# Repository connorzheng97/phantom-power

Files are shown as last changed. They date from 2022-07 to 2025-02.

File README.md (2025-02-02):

# What is this

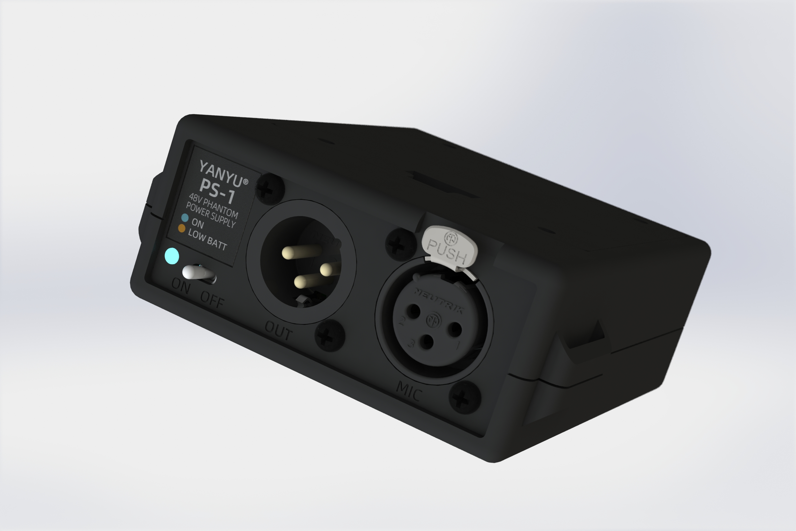
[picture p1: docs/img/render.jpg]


This is a 3-AA-battery powered phantom power supply. It was intended for use with wireless microphone beltpacks to provide high quality 48V phantom power to large condenser microphones and enable them to be used wirelessly, or as a standalone unit. It's also suitable for DI boxes, small condenser microphones and anything requiring phantom power.

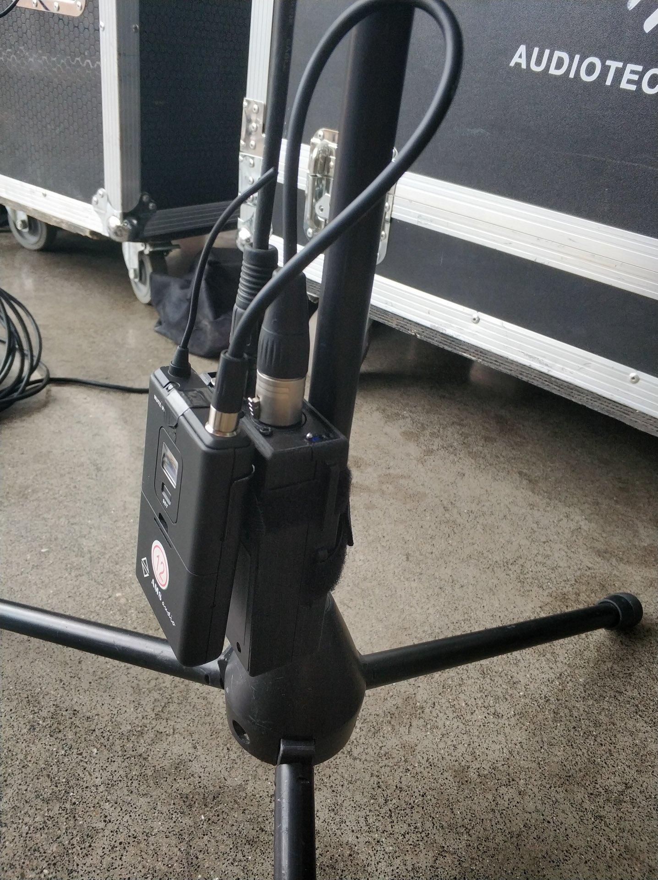
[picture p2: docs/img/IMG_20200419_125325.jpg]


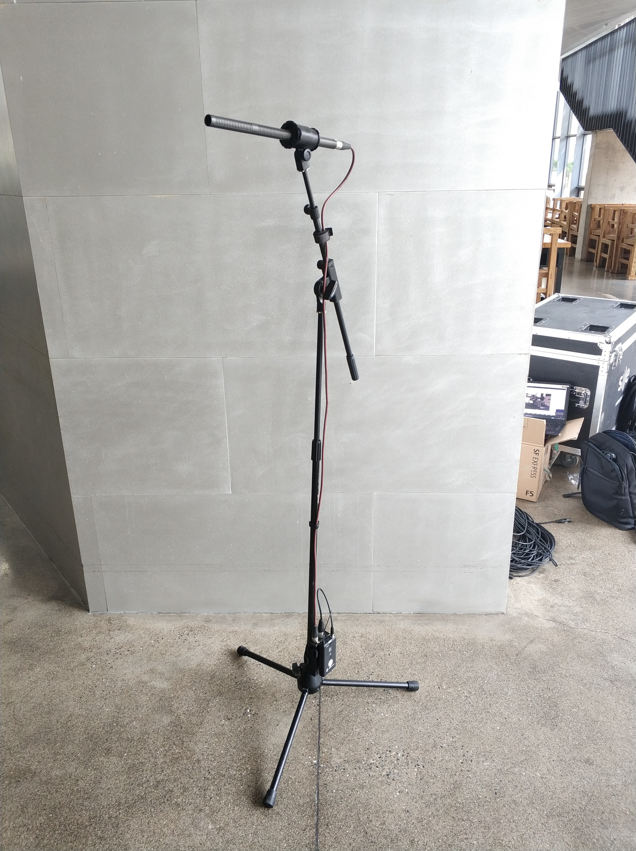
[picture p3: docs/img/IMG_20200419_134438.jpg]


This is a complete design with schematic, PCB and enclosure. Files are production-ready, with BOM. Design of this project begun in 2019 and final test was done on December of 2021. Batch production was planned but hasn't been carried out, as newer wireless microphone beltpacks has begun to incorporate built-in phantom power circuits (although usually not at full 48V), and COVID has had a major impact on touring industry.

# The Specs
- Power Source: 3x AA Batteries, alkaline is recommended. Ni-Mh rechargeable can also be used.
- Battery Run Time: depends on load and actual battery capacity, 5 to 72 hours typically
- Battery Indicator: yes, two LEDs for normal and low battery
- Power Output: IEC 61938, 48VDC ±2V
- Phantom Resistor: 6.81K
- Current: up to about 14mA at short-circuit
- Noise: < 100uVpp
- EMI: not tested

# The Design
## Overall Design

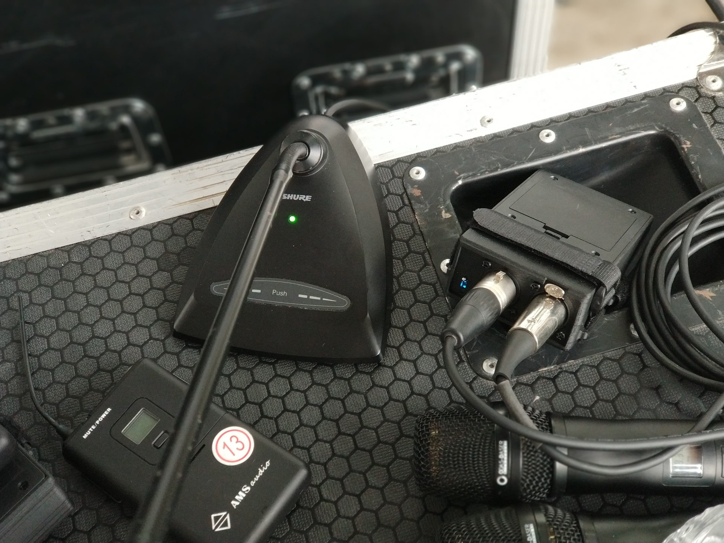
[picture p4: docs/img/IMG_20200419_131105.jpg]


A simple power supply box with XLR-in (connects to device requiring phantom power), XLR-out (no DC bias, connect to audio input of next stage), a power switch and a battery voltage indicator. The switch is partly recessed to avoid accidental operation. The colors of the battery indicator are ice-blue and orange, which are color-blind friendly. On the side of the box are 2 ears where you can thread in a hook-and-loop nylon cable tie to form a loop and strap the box to wireless beltpack and microphone stand or other fixation points.

## Schematic and PCB
Schematic and PCB were done with KiCAD 5. A [PDF version of the schematic](./docs/phantom_v1.pdf) is available for view under the `docs` folder.

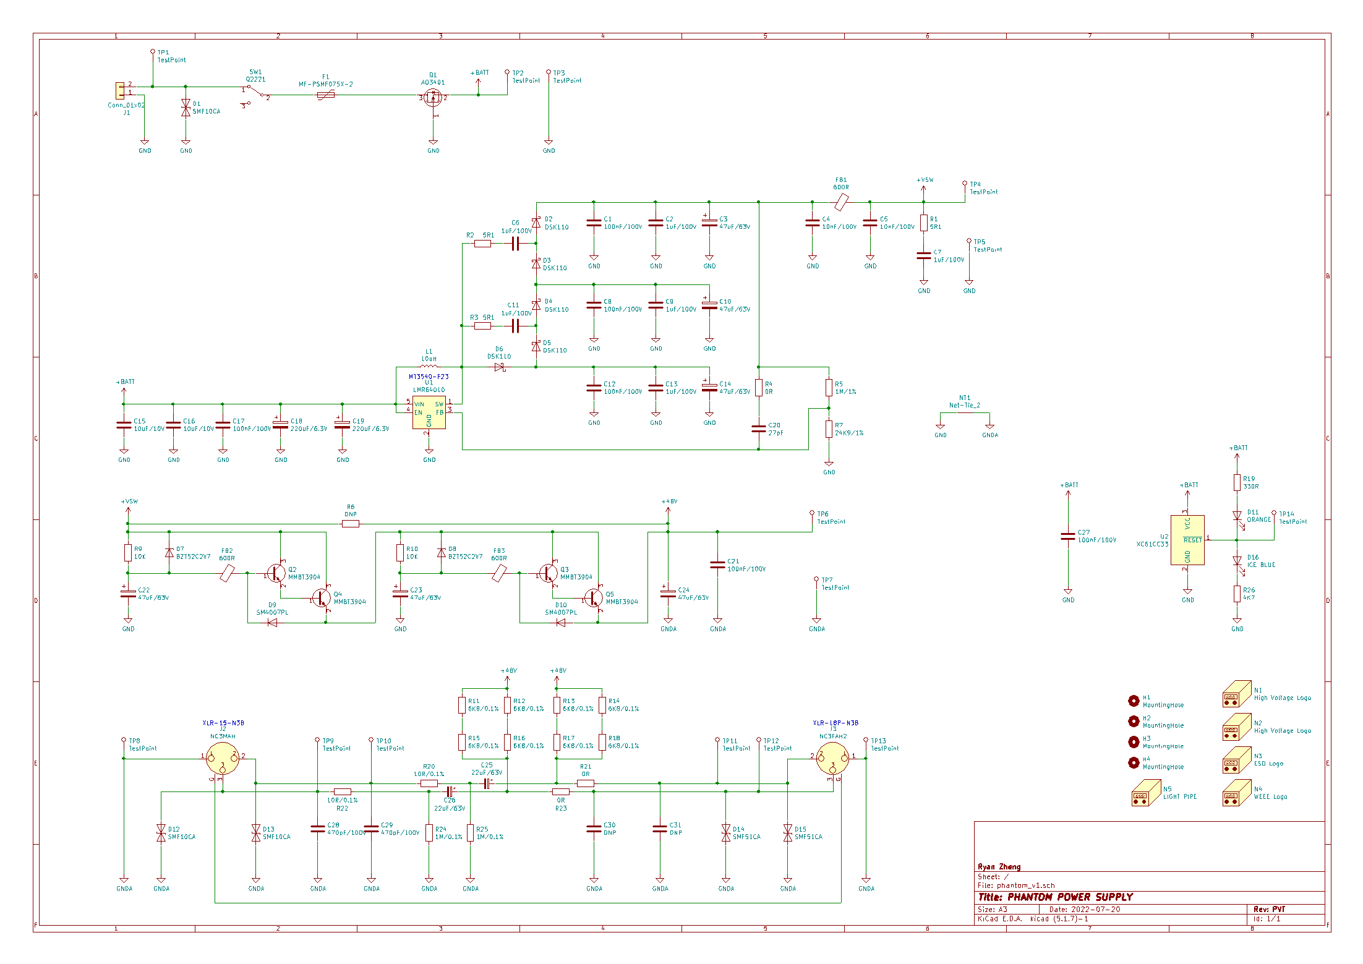
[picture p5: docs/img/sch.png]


Circuit consists of a simple boost converter with added 3-stage diode voltage multiplier, a high voltage LDO, and a 2-stage Darlington capacitance multiplier for lowest noise possible. Protection circuitry and battery voltage indication were also added. A P-MOS blocks reverse battery, followed by a PPTC resettable fuse and transient suppression.

PCB is a normal 1.6mm 2-layer PCB.

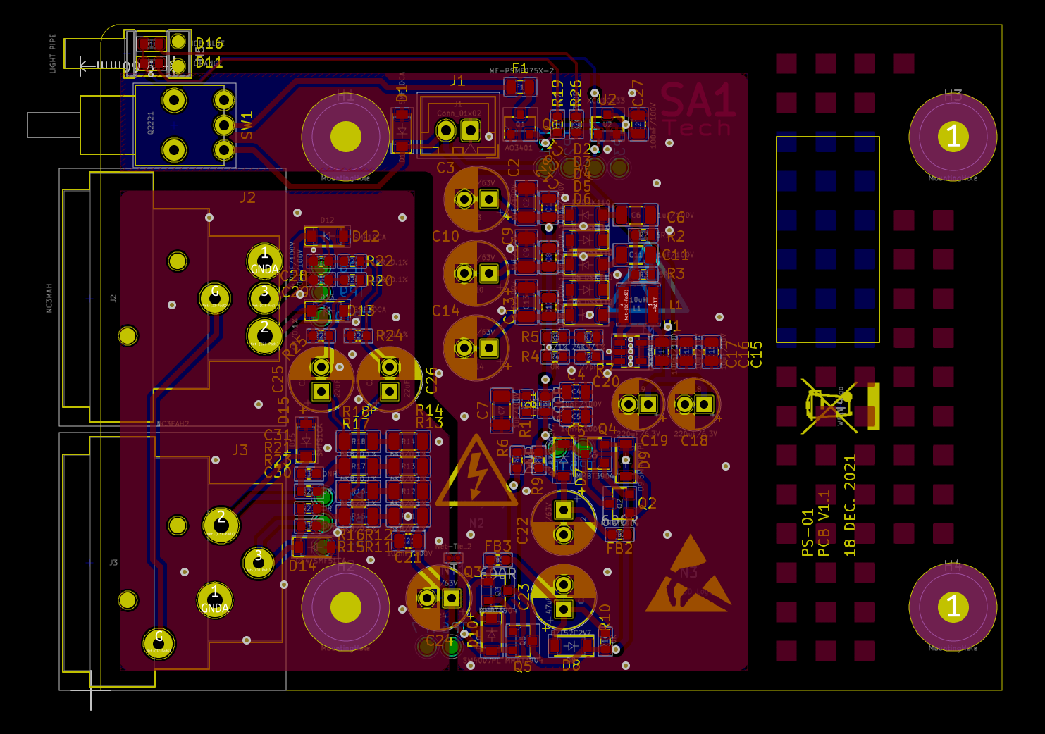
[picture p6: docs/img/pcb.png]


## Mechanical Design
Enclosure design was done with Solidworks 2018. STEP and STL files are also provided in the `mech` folder. The design is mostly complete, and should be injection-molding ready, with no draft angle in design file. 

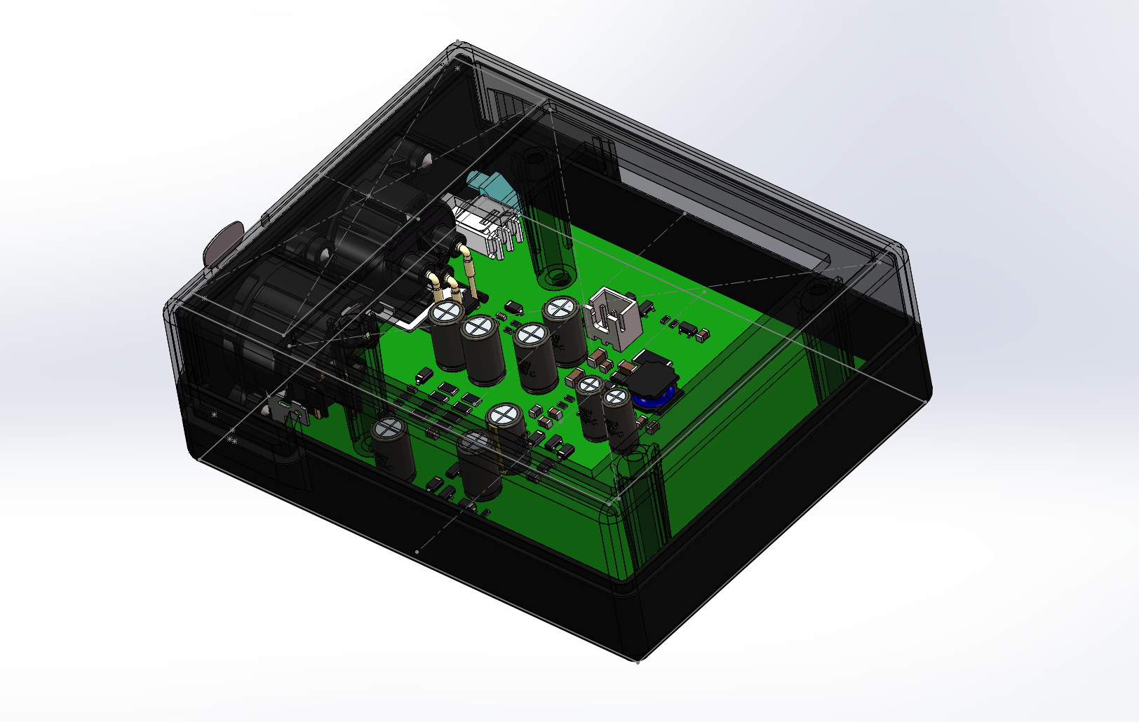
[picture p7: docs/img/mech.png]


The PCB is held down to the base part by boss from top part, which are held down to base part by self-tapping screws. The holes in the bosses are through, which are also used to mount the battery holder. The front panel is held in place by groves on both large parts. The battery holder is an off-the-shelf one which can be bought on Taobao or AliExpress. XLR connectors are fixed to front panel with self-tapping screws.

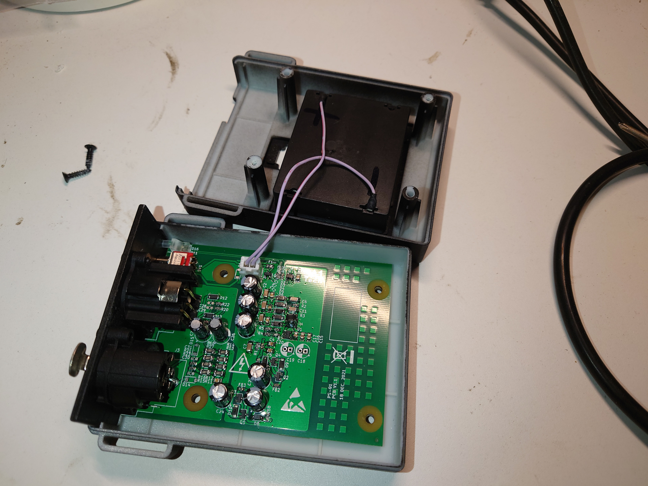
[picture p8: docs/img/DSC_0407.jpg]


# Make Your Own
You can fabricate the PCB and have it partly assembled by a PCB fab such as PCBWay(JDB PCB) or JLC-PCB. Solder only the common SMT parts at the fab, which I found to be the most cost-saving. A gerber file set is included in the `output` folder in the hardware design files. Other parts can be sourced from LCSC or another distributor. Hand soldering is mostly easy except the VSSOP LDO may be a little bit annoying. Alternative part number may be found in schematic.

Enclosure can be 3D-printed either at home or by a professional service. For FDM 3D-printing, remove small details that are not printable. Print top part upside down with support.

A BOM for assembling can be found under the `docs` folder. A interactive BOM for the pcb can be found in the `ibom` folder under the `docs` folder.

## Assembling
1. Push light pipe onto PCB
2. Mount front panel to XLR connectors with 4 ST2.9x8 screws
3. Solder XH2.54 pigtail to battery holder
4. Mount battery holder onto top part of box with 4 ST3x10 screws
5. Place PCB and front panel into base part
6. Plug in battery XH2.54 plug
7. Screw top and base part together with 4 ST3x12 screws
8. Thread in hook-and-loop nylon cable tie

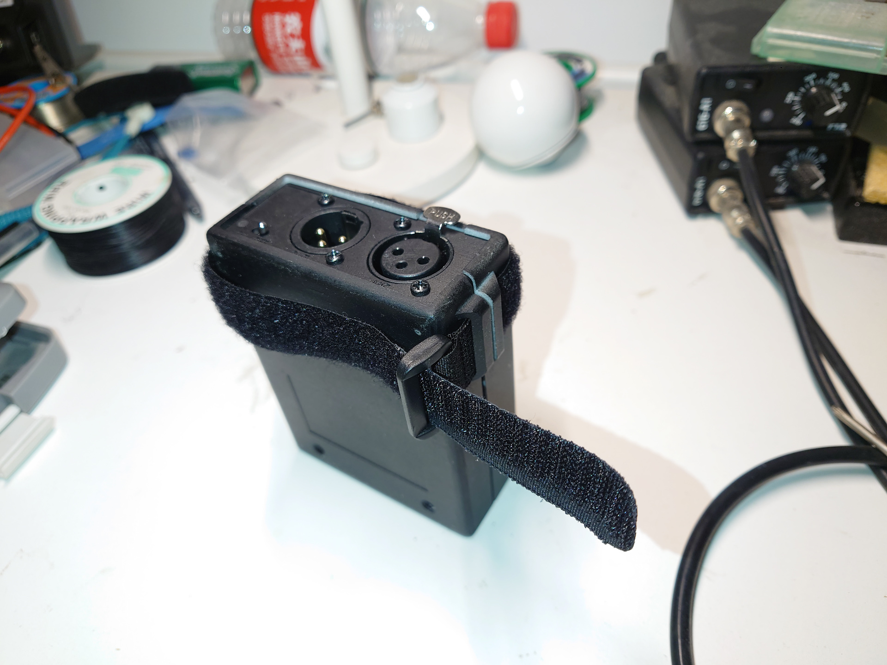
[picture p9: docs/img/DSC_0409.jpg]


# Use of This Repo
This repo is licensed under CERN-OHL-W v2. In addition, consider buying me a drink if you like this design. You can credit back to my personal website as well if you wish.

This source describes Open Hardware and is licensed under the CERN-OHLW v2 

You may redistribute and modify this documentation and make products using it under the terms of the CERN-OHL-W v2 (https:/cern.ch/cern-ohl). 

This documentation is distributed WITHOUT ANY EXPRESS OR IMPLIED WARRANTY, INCLUDING OF MERCHANTABILITY, SATISFACTORY QUALITY AND FITNESS FOR A PARTICULAR PURPOSE. 
Please see the CERN-OHL-W v2 for applicable conditions. 

As per CERN-OHL-W v2 section 4.1, should You produce hardware based on these sources, You must maintain the Source Location visible on the external case of the phantom power supply or other product you make using this documentation.

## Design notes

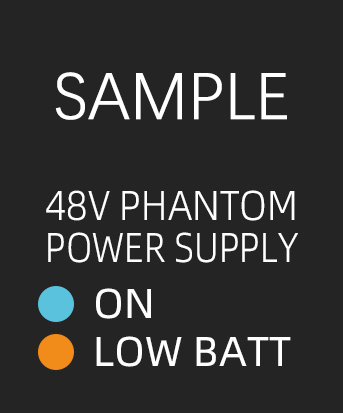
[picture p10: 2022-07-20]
mech/STICKER_FRONT.jpg

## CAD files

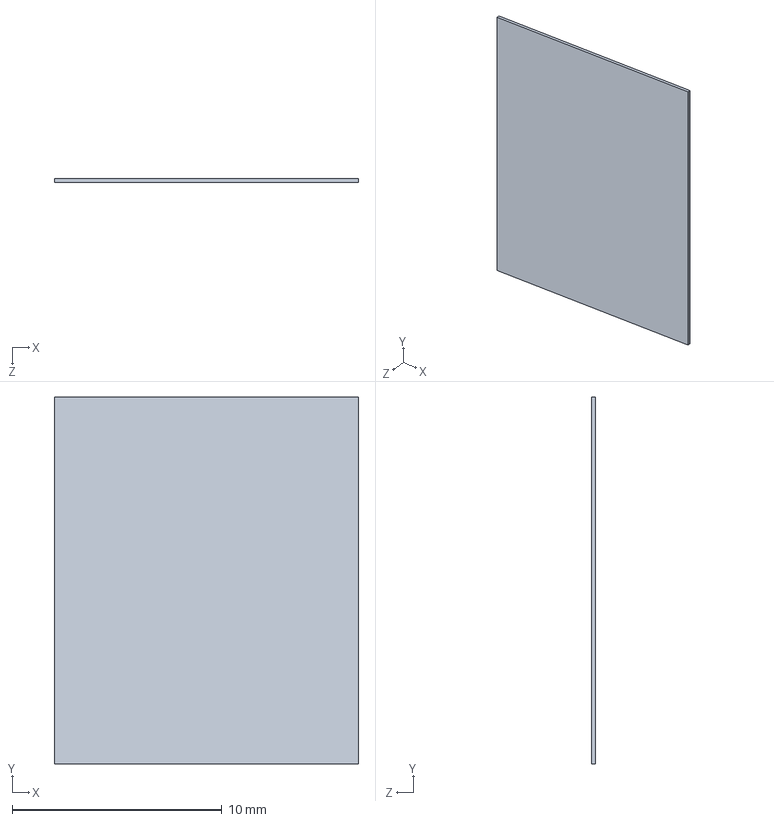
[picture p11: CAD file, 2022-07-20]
mech/V1_STICKER_FRONT.SLDPRT
14.5 x 17.5 x 0.2 mm

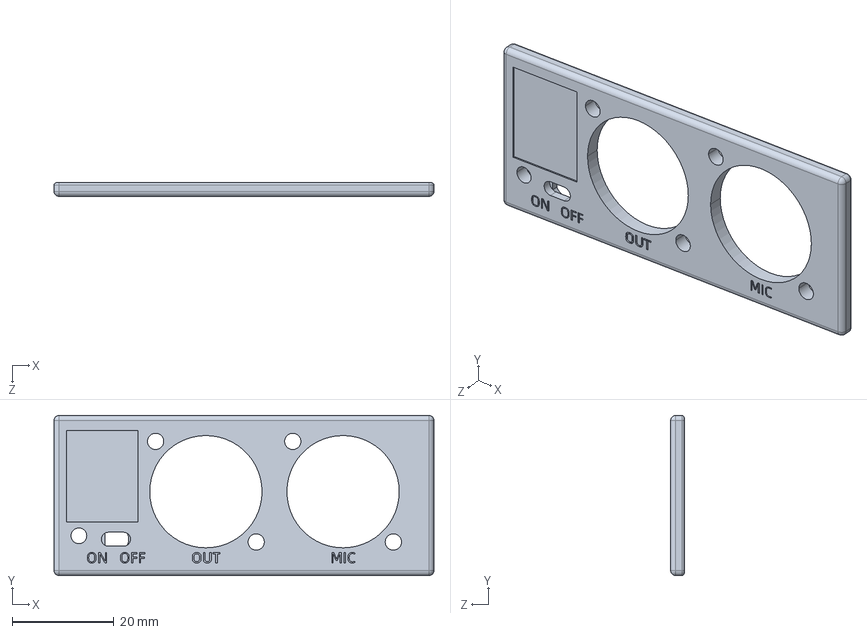
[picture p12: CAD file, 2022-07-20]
mech/V1_FRONT.STEP
74.8 x 31.5 x 2.70 mm

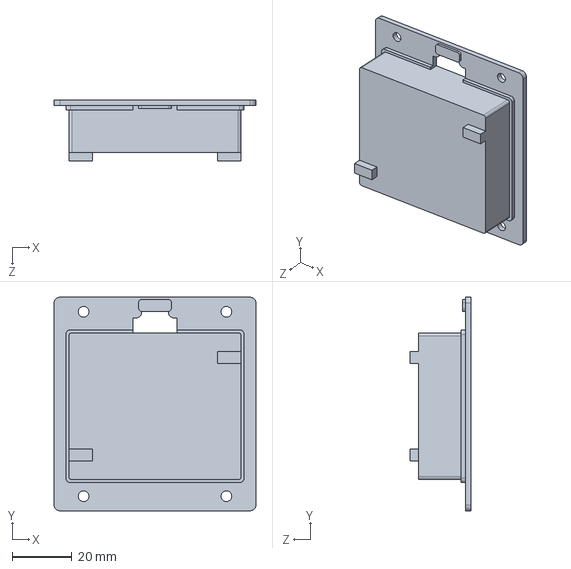
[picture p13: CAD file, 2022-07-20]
mech/BATTERY_HOLDER.SLDPRT
67.9 x 71.8 x 20.6 mm

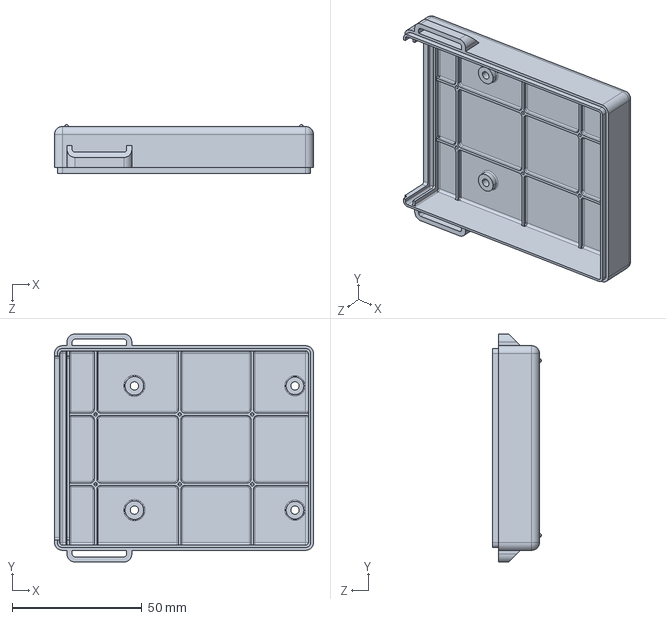
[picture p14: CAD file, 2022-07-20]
mech/V1_BASE.STEP
100.0 x 88.0 x 18.9 mm

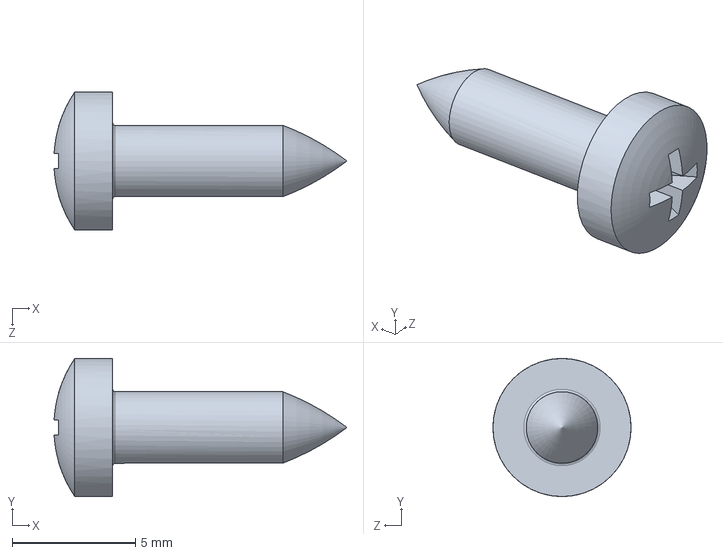
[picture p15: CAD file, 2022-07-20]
mech/ST2.9X9.5 H C-C.sldprt
11.9 x 5.60 x 5.60 mm

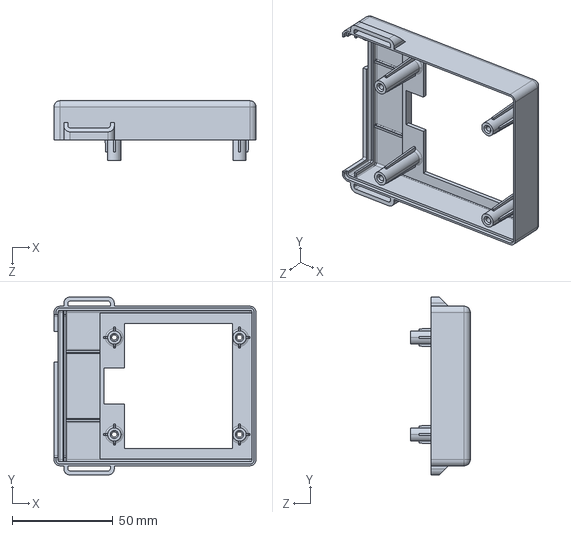
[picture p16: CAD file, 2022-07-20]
mech/V1_TOP.STEP
100.0 x 88.0 x 29.5 mm

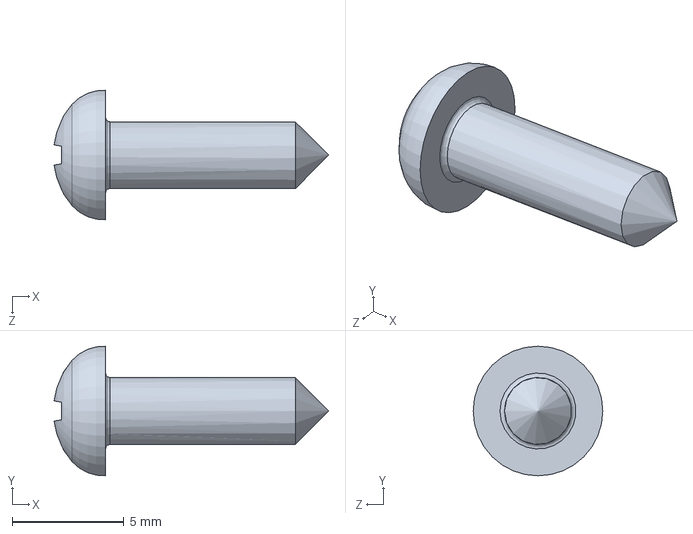
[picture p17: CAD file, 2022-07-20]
mech/M3X10-N.sldprt
12.3 x 5.80 x 5.80 mm

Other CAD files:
mech/V1_BASE.SLDPRT
mech/V1_BASE.STL
mech/V1_FRONT.SLDPRT
mech/V1_FRONT.STL
mech/V1_TOP.SLDPRT
mech/V1_TOP.STL

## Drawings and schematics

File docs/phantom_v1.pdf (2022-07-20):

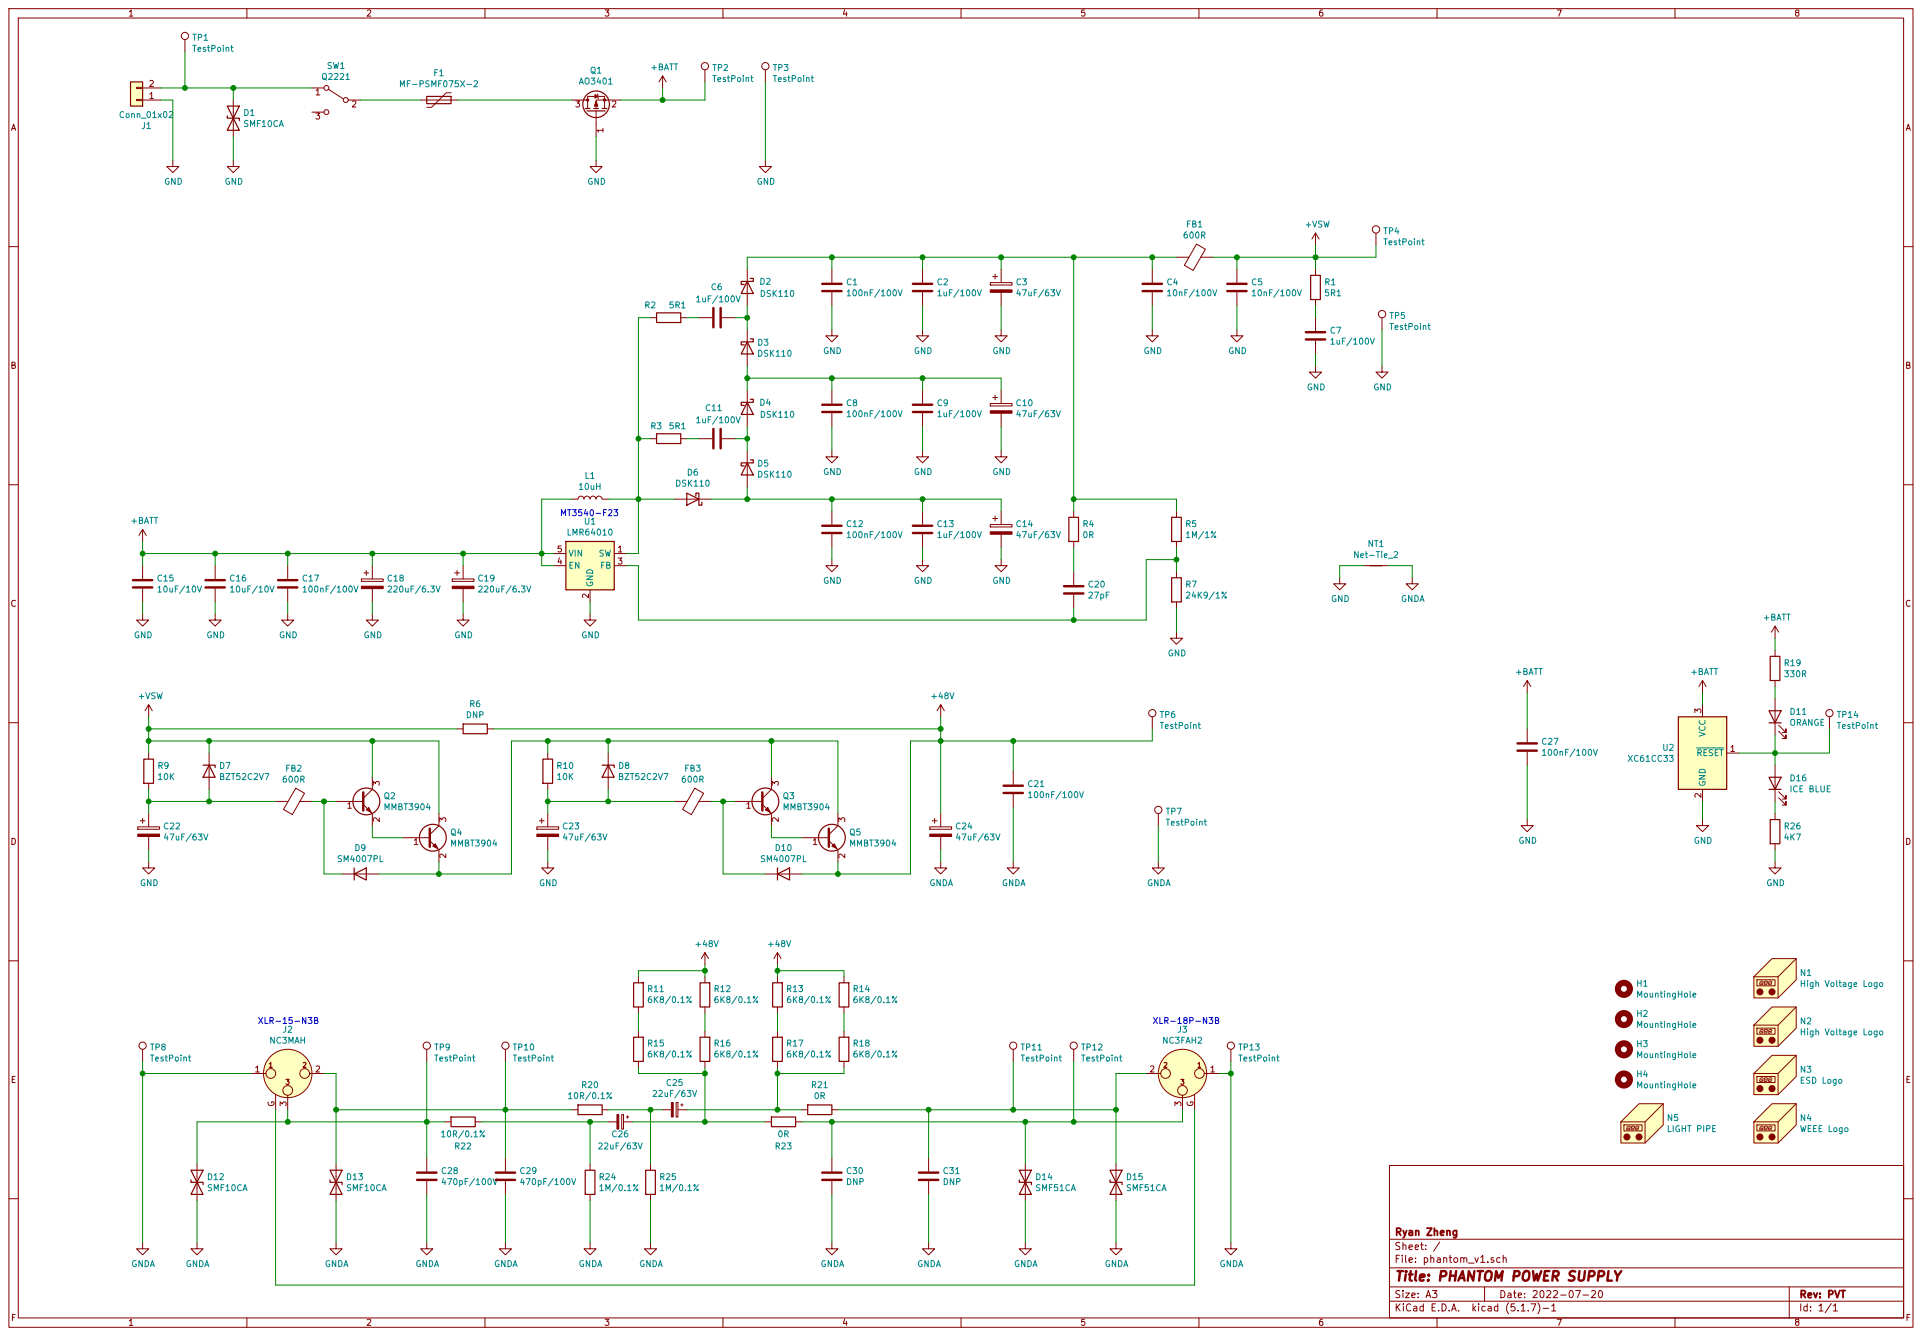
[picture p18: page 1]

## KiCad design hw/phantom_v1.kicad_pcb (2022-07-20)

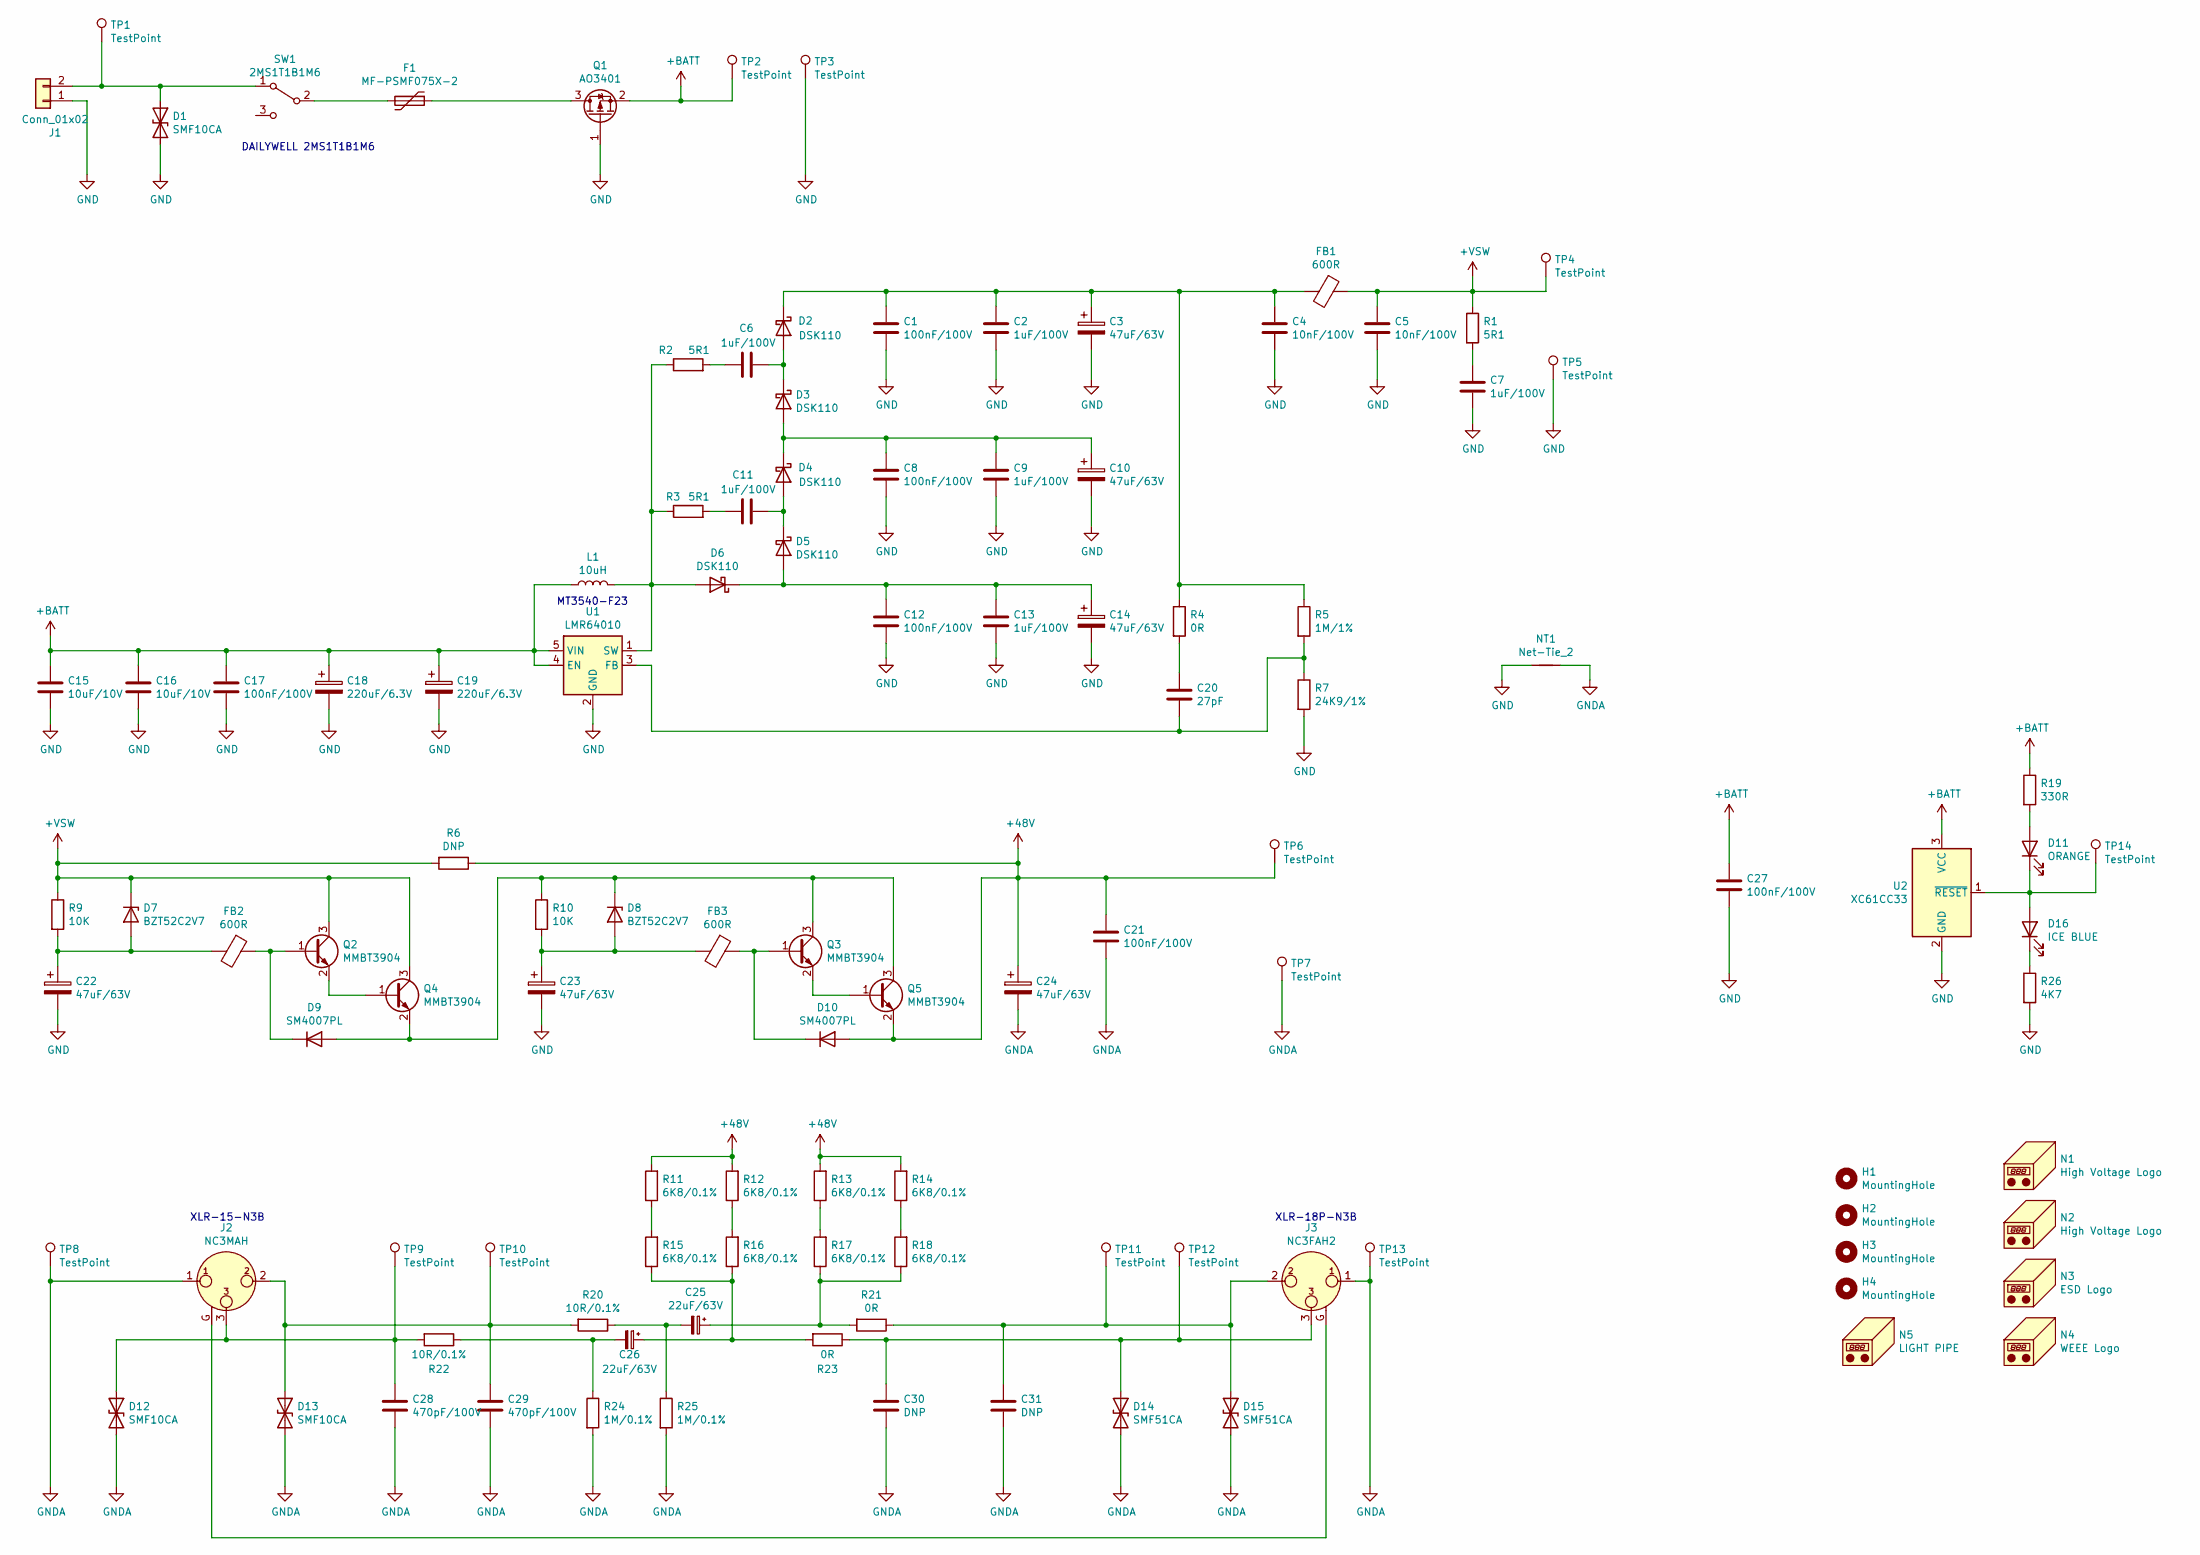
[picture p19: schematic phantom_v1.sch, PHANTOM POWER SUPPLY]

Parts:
C1, C8, C12, C17, C21, C27: 100nF/100V; C_0805_2012Metric
C2, C6, C7, C9, C11, C13: 1uF/100V; C_1206_3216Metric
C3, C10, C14, C22, C23, C24: 47uF/63V; CP_Radial_D6.3mm_P2.50mm
C4, C5: 10nF/100V; C_0805_2012Metric
C15, C16: 10uF/10V; C_0805_2012Metric
C18, C19: 220uF/6.3V; CP_Radial_D5.0mm_P2.00mm
C20: 27pF; C_0603_1608Metric
C25, C26: 22uF/63V; CP_Radial_D6.3mm_P2.50mm
C28, C29: 470pF/100V; C_0603_1608Metric
C30, C31: DNP; C_0603_1608Metric
D1, D12, D13: SMF10CA; D_SOD-123
D2, D3, D4, D5, D6: DSK110; D_SOD-123
D7, D8: BZT52C2V7; D_SOD-123
D9, D10: SM4007PL; D_SOD-123
D11: ORANGE; LED_0603_1608Metric
D14, D15: SMF51CA; D_SOD-123
D16: ICE BLUE; LED_0603_1608Metric
F1: MF-PSMF075X-2; Fuse_0805_2012Metric
FB1, FB2, FB3: 600R; L_0603_1608Metric
H1, H2, H3, H4: MountingHole; MountingHole_3.2mm_M3
J1: Conn_01x02; JST_XH_B2B-XH-A_1x02_P2.50mm_Vertical
J2: NC3MAH; Jack_XLR_Neutrik_NC3MAH_Horizontal
J3: NC3FAH2; Jack_XLR_Neutrik_NC3FAH2_Horizontal
L1: 10uH; PowerInductor_SWPA40XX
N1, N2: High Voltage Logo; LOGO-Warning-High_Voltage-Silk
N3: ESD Logo; ESD-Logo_8.9x8mm_SilkScreen
N4: WEEE Logo; WEEE-Logo_5.6x8mm_SilkScreen
N5: LIGHT PIPE; MECH-Light_pipe_6.35mm
NT1: Net-Tie_2; NetTie-2_SMD_Pad0.5mm
Q1: AO3401; SOT-23
Q2, Q3, Q4, Q5: MMBT3904; SOT-23
R1, R2, R3: 5R1; R_0603_1608Metric
R4, R21, R23: 0R; R_0603_1608Metric
R5: 1M/1%; R_0603_1608Metric
R6: DNP; R_0603_1608Metric
R7: 24K9/1%; R_0603_1608Metric
R9, R10: 10K; R_0603_1608Metric
R11, R12, R13, R14, R15, R16, R17, R18: 6K8/0.1%; R_1206_3216Metric
R19: 330R; R_0603_1608Metric
R20, R22: 10R/0.1%; R_0603_1608Metric
R24, R25: 1M/0.1%; R_0603_1608Metric
R26: 4K7; R_0603_1608Metric
SW1: 2MS1T1B1M6; Switch-2MS1T2B2M6-SPDT-ONON-THT
TP1, TP2, TP3, TP4, TP5, TP6, TP7, TP8, TP9, TP10, TP11, TP12, TP13, TP14: TestPoint; TestPoint_Pad_D1.5mm
U1: LMR64010; SOT-23-5
U2: XC61CC33; SOT-23

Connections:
+48V: C21.1, C24.1, D10.2 (A), Q5.2 (E), R6.1, R11.2, R12.2, R13.2, R14.2, TP6.1
+BATT: C15.1, C16.1, C17.1, C18.1, C19.1, C27.1, L1.1, Q1.2 (S), R19.1, TP2.1, U1.4 (EN), U1.5 (VIN), U2.3 (VCC)
+VSW: C5.1, D7.1 (K), FB1.1, Q2.3 (C), Q4.3 (C), R1.1, R6.2, R9.1, TP4.1
GND: C1.2, C2.2, C3.2, C4.2, C5.2, C7.2, C8.2, C9.2, C10.2, C12.2, C13.2, C14.2, C15.2, C16.2, C17.2, C18.2, C19.2, C22.2, C23.2, C27.2, D1.2 (A2), J1.1, NT1.1, Q1.1 (G), R7.2, R26.2, TP3.1, TP5.1, U1.2 (GND), U2.2 (GND)
GNDA: C21.2, C24.2, C28.2, C29.2, C30.2, C31.2, D12.2 (A2), D13.2 (A2), D14.2 (A2), D15.2 (A2), J2.1, J3.1, NT1.2, R24.2, R25.2, TP7.1, TP8.1, TP13.1
unnamed: C1.1, C2.1, C3.1, C4.1, D2.1 (K), FB1.2, R4.1, R5.1
unnamed: C6.1, R2.2
unnamed: C6.2, D2.2 (A), D3.1 (K)
unnamed: C7.1, R1.2
unnamed: C8.1, C9.1, C10.1, D3.2 (A), D4.1 (K)
unnamed: C11.1, R3.2
unnamed: C11.2, D4.2 (A), D5.1 (K)
unnamed: C12.1, C13.1, C14.1, D5.2 (A), D6.1 (K)
unnamed: C20.1, R4.2
unnamed: C20.2, R5.2, R7.1, U1.3 (FB)
unnamed: C22.1, D7.2 (A), FB2.2, R9.2
unnamed: C23.1, D8.2 (A), FB3.2, R10.2
unnamed: C25.1, R17.1, R18.1, R21.2
unnamed: C25.2, R20.1, R25.1
unnamed: C26.1, R15.1, R16.1, R23.2
unnamed: C26.2, R22.1, R24.1
unnamed: C28.1, D12.1 (A1), J2.3, R22.2, TP9.1
unnamed: C29.1, D13.1 (A1), J2.2, R20.2, TP10.1
unnamed: C30.1, D14.1 (A1), J3.3, R23.1, TP12.1
unnamed: C31.1, D15.1 (A1), J3.2, R21.1, TP11.1
unnamed: D1.1 (A1), J1.2, SW1.1 (A), TP1.1
unnamed: D6.2 (A), L1.2, R2.1, R3.1, U1.1 (SW)
unnamed: D8.1 (K), D9.2 (A), Q3.3 (C), Q4.2 (E), Q5.3 (C), R10.1
unnamed: D9.1 (K), FB2.1, Q2.1 (B)
unnamed: D10.1 (K), FB3.1, Q3.1 (B)
unnamed: D11.1 (K), D16.2 (A), TP14.1, U2.1 (~RESET)
unnamed: D11.2 (A), R19.2
unnamed: D16.1 (K), R26.1
unnamed: F1.1, Q1.3 (D)
unnamed: F1.2, SW1.2 (B)
unnamed: J2.G, J3.G
unnamed: Q2.2 (E), Q4.1 (B)
unnamed: Q3.2 (E), Q5.1 (B)
unnamed: R11.1, R15.2
unnamed: R12.1, R16.2
unnamed: R13.1, R17.2
unnamed: R14.1, R18.2

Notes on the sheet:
MT3540-F23
XLR-18P-N3B
XLR-15-N3B
DAILYWELL 2MS1T1B1M6

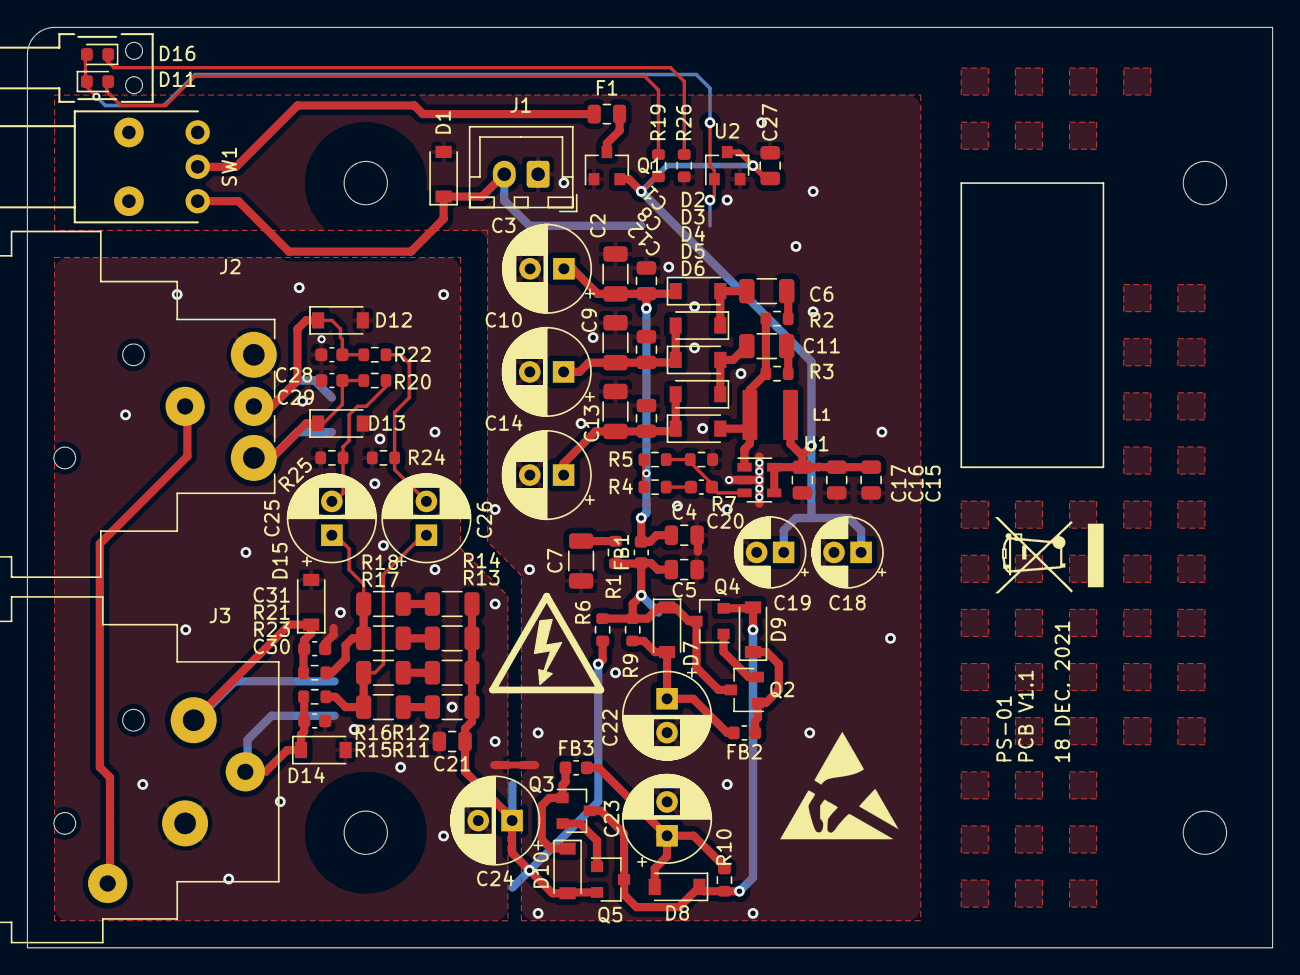
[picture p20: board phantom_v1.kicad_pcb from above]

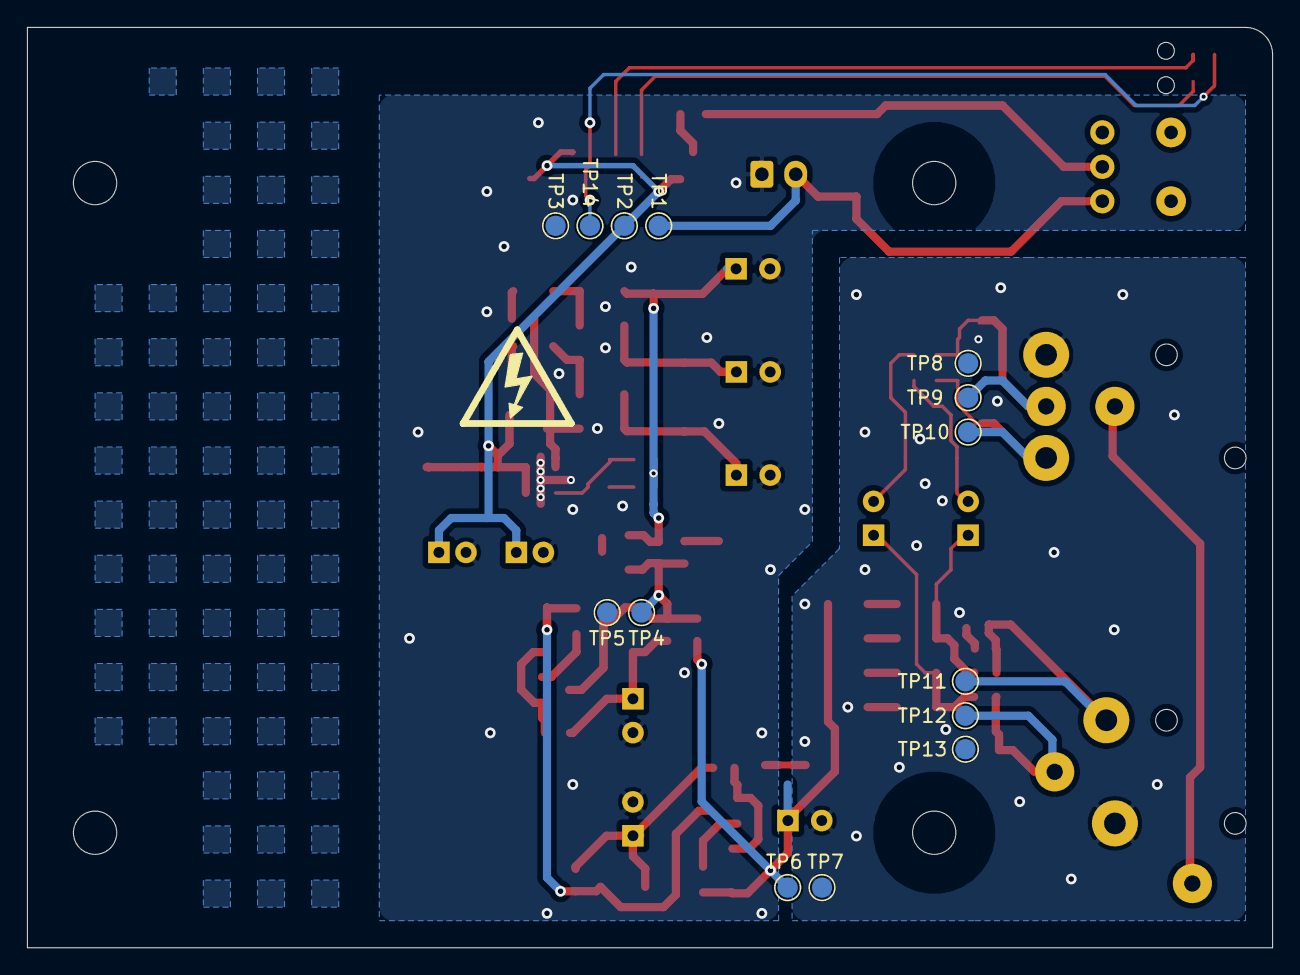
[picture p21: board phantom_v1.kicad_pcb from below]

Board: 2 copper layers, 92.0 x 68.0 mm, 112 parts (15 on the bottom side), 42 nets.
